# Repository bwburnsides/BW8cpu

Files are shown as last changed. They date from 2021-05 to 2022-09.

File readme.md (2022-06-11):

# 👾 BW8cpu

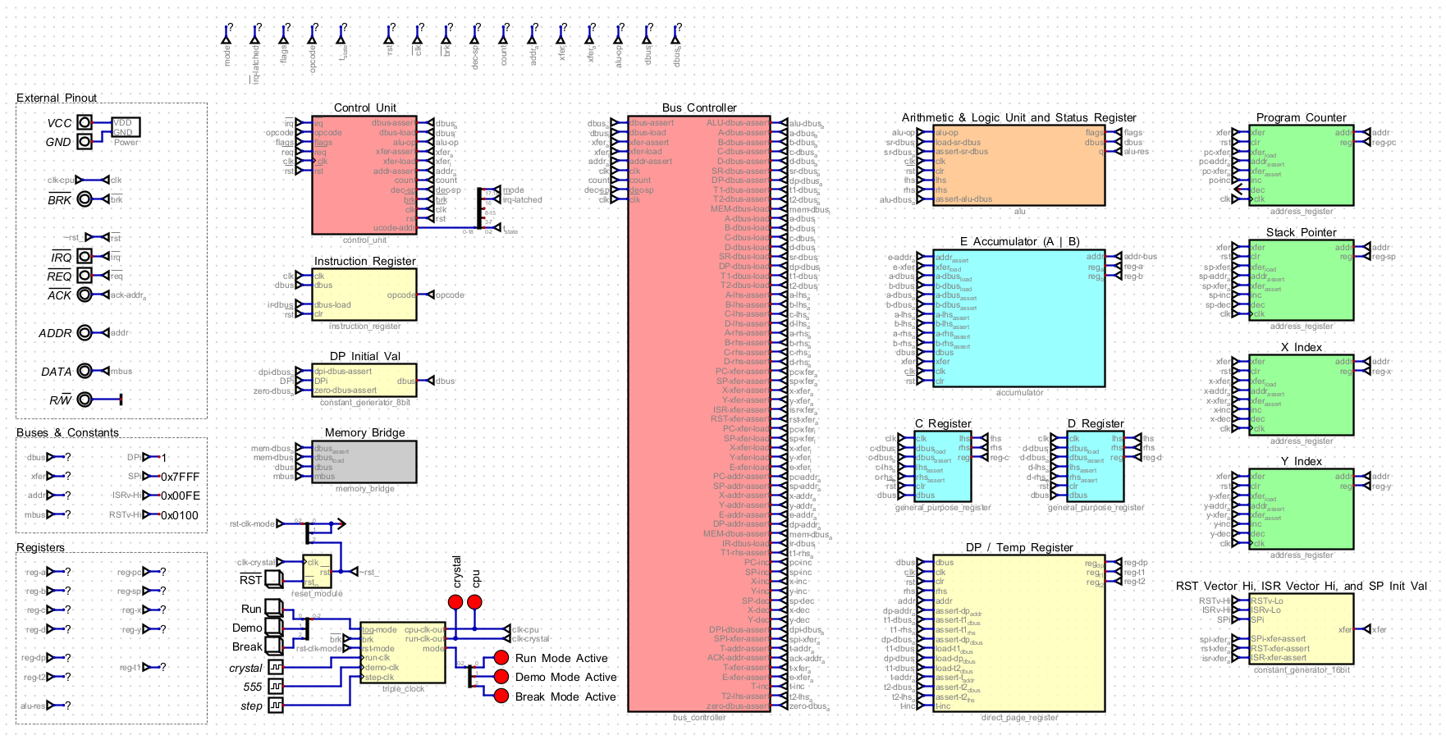
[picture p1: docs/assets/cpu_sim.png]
BW8cpu Digital Simulation top level view


The BW8cpu is a homemade CPU built with discrete CMOS logic chips on custom PCBs. It has a target clock rate of approximately 4 MHz, and is comparable to venerable 8-bit CPUs such as the MOS 6502, Zilog Z80, Motorola 6809, and Intel 8088.

A larger computer system is built around the CPU in the form of a full peripheral suite that allows the BW8cpu to function as a machine similar to the Commodore 64, Apple II, or NES. From a hardware perspective, the BW8cpu matches or maybe exceeds these systems in capability and usability in many regards. Its my hope that the system will eventually exceed its predecessors from a software perspective as well.

The project is originally inspired by Ben Eater's [8-bit breadboard CPU](https://eater.net/8bit) and his [breadboard MOS 6502 computer](https://eater.net/6502). However, ultimately the micro-architecture takes more cues from James Sharman's [8-bit pipelined CPU](https://www.youtube.com/watch?v=3iHag4k4yEg&list=PLFhc0MFC8MiCDOh3cGFji3qQfXziB9yOw). This project would not be possible without the support of many individuals present on James' Discord server, notably [rj45](https://github.com/rj45/rj32), Quandary, Artentus, and [Louis Jewett](https://www.youtube.com/channel/UCsxBT-Jh5pMDU-uEN_EUXtg/featured).

This project is extremely ambitious and long running. This repository will maintain documentation and descriptions of the existent and planned features, as well as supporting schematics and source code files.

## Features

- 8-bit CPU with 20-bit memory addressing, 8-bit IO addressing
- Up to 512 opcodes across 50 instructions (CISC ISA)
- 4x 8-bit General Purpose Registers (A, B, C, D)
- Full 16-bit Stack Pointer (SP) and Program Counters (PC)
- Configurable Direct Page addressing (movable Zero Page)
- Two 16-bit General Purpose Pointers (X, Y)
- 16-function ALU with 4 flags (Carry, Zero, Overflow, Sign)
- IRQ and NMI inputs
- Bus arbitration, allowing for DMA control
- Thin supervisor mode

## Architecture Overview

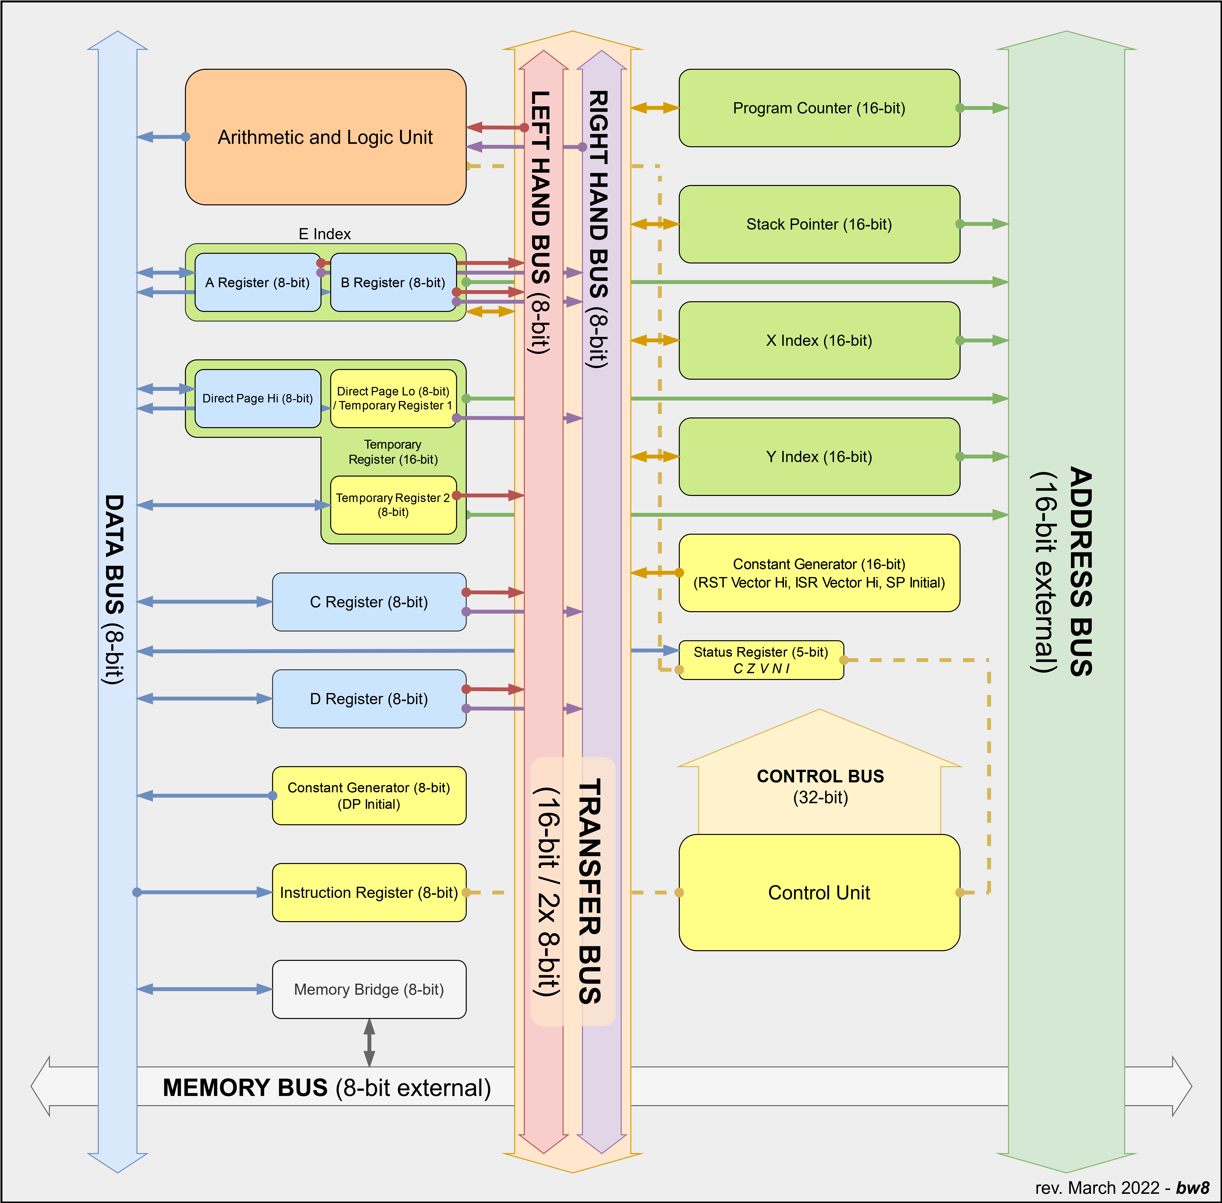
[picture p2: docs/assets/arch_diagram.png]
architecture diagram of BW8cpu


- [von Neumann architecture](https://en.wikipedia.org/wiki/Von_Neumann_architecture) with shared program and data address space
- Vertical microcode (heavily encoded) with 32-bit Control Bus
- Direct to address bus assertions without MAR
- No instruction pipelining - up to 8 clocks / instruction

## Expansion & Peripherals

- IO is memory mapped
- Reference Memory Map features:
    - 256 bytes IO space
    - 31.75 KB fixed RAM space
    - 32 KB total bankable space (4x 8 KB banks)
- Plans for full peripheral suite:
    - Programmable Interrupt Controller with 8 interrupt sources
    - VGA Video Card with output at 320x240 with 40x30 tilemap, hardware scrolling, and hardware sprite support
    - PS/2 keyboard input
    - Programmable Sound Generator with 4 voices
    - SPI Controller for SD card-based persistent storage
    - RS-232 UART networking interface
    - DMA Controller for fast block copies

## Tool Chain

- Simulation with [Digital](https://github.com/hneemann/Digital)
- Emulation with C
- Schematics and PCB layout with [KiCAD](https://www.kicad.org/)
- Assembler with [customasm](https://github.com/hlorenzi/customasm)
- Microcode development with Python

## Explore

🔧 [ISA](docs/instruction-set-architecture.md)

🧮 [ALU](docs/arithmetic-logic-unit.md)

🚥 [CU](docs/control-unit.md)

📺 [VGA](docs/video-card.md)

💾 [SPI](docs/spi.md)

📢 [PSG](docs/sound-card.md)

📡 [UART](docs/uart.md)

🎛 [Emulator](docs/emulator.md)

🎯 [Simulator](docs/simulator.md)

🗺 [Memory Map](docs/memory-map.md)

🏗 [Assembler](docs/assembler.md)

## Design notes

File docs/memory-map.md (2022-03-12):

# 🗺 Memory Map

The memory map was designed to maximize contiguous RAM space and provide ample banking to work around the 64 KB addressing limitation imposed by the 16-bit address bus.

    $E000 - $FFFF:   Banked RAM (8K)
    $C000 - $DFFF:   Banked RAM (8K)
    $A000 - $BFFF:   Banked RAM (8K)
    $8000 - $9FFF:   Banked RAM (8K)
    $0100 - $7FFF:   Fixed RAM (31.75K)
    $0000 - $00FF:   MMIO (256B)

This memory map provides just-shy of 32 KB of contiguous fixed RAM, and then another 32 KB of contiguous banked RAM in the form of 4x 8 KB banked regions. The first page of memory is allocated to memory mapped IO, the only form of IO in the system. Specifications of the active page for each bank will be done via 4x 1-byte registers in the MMIO region. This region will be divided into 16 equally sized IO ports, each afforded 16 IO registers. Here is a potential utilization scheme for the IO ports:

1. Programmable Interrupt Controller 1 (PIC)
2. Programmable Interrupt Controller 2
3. Memory Mapping Unit (MMU)
4. [UART](uart.md)
5. [SPI Bus](spi.md)
6. [Video Card](video-card.md)
7. [Sound Card](sound-card.md)
8. Sound Card 2
9. DMA Controller
10. PS/2 Keyboard Controller
...

Note that these IO devices largely correspond to those mentioned in the [readme](../readme.md). The new comers are the PIC and the MMU. The PIC is responsible for coalescing interrupts from multiple sources into a single IRQ input for the CPU. It contains registers for specifying the addresses of unique ISRs for each interrupt source. When the CPU reads from its ISR Vector, the PIC is responsible for making the highest-priority, non-masked, active interrupt's ISR address available at the vector location. The MMU contains registers used to configure the active page in each bankable location, as described above.

Note that the Sound Card and the PIC each use 2 IO ports a piece - this is due to the number of expected registers each device will require. I've elected to keep the number of registers per IO port relatively small, as doing so allows for devices which do in fact only need a few registers to be integrated in a less wasteful manner.

Another useful aspect of this memory configuration is that nearly the entire address space is covered by RAM, rather than ROM. This allows greater flexibility and usage of the address space, as all regions will allow writes. In order to facilitate this, a sub circuit will hold the CPU in reset while a ROM is copied into RAM. At runtime, this ROM becomes inactive. The copier circuit will initialize the entire low 32 KB of the address space, which has the side effect that the ROM can be used to initialize writable IO registers are pre-runtime.

The initial location of the DP and the SP are specified by the state of Constant Generators internal to the CPU. These are configurable via DIP switches on the appropriate CG boards. However, both values can be modified at runtime, should the user decide to relocate the stack or direct page. This can be done with the appropriate MOV opcodes made available in the Instruction Set.

The bank select registers will use all 8-bits to select a region of physical RAM to map into the bank regions. As the regions are 8 KB in size, this gives 2^8 * 8 KB = 2 MB of physical RAM accessible to the system. In fact, even the low 31.75 KB of RAM will map into this physical space.

If the decoded address belongs to the highest 32 KB of the physical RAM, then any writes will also be pushed through to VRAM. Effectively, this region shadows VRAM. It allows for any of the four banks to be used for VRAM manipulation, and it removes all potential contention issues for VRAM reads.

Both this, as well as the ROM copy-on-reset, are examples of RAM shadowing. The shadow regions are shown in blue, below.

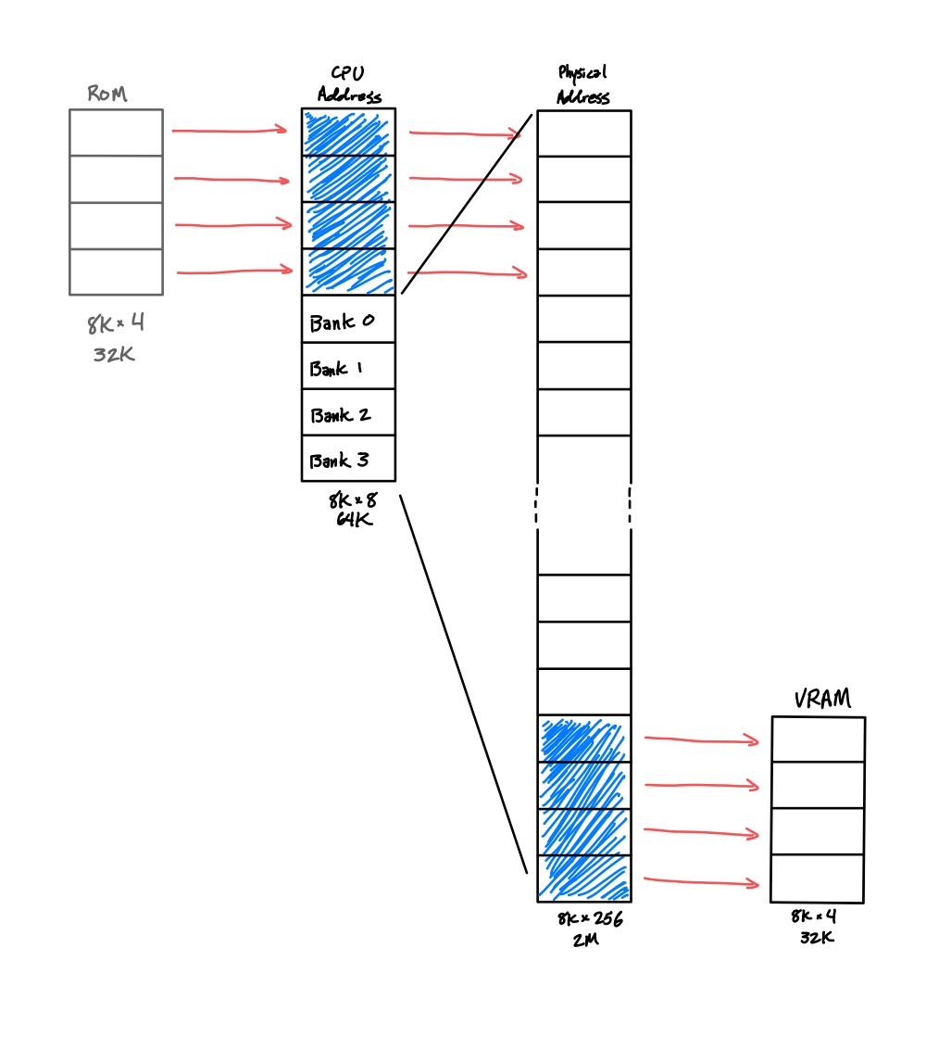
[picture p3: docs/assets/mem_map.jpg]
mem map diagram of BW8comp


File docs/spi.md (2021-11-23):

# 💾 SPI

The SPI peripheral's main reason for existing is to provide a hardware interface to SD cards, such that they may be used as a persistent storage medium for the BW8cpu.

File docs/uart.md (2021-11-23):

# 📡 UART

The UART allows for bidirectional communication between the CPU and another computer or controller.

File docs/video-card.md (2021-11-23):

# 📺 VGA

The premier BW8cpu peripheral is the VGA video card. This peripheral is similar to the NES's PPU. It runs in a reduced VGA 640x480 mode, producing an output of 320x240 pixels. Although a portion of the MMIO's 256 byte page will be allocated to the video card, the frame buffer will be accessible as one of the 16 KB banks in the top 16 KB of the address space. The card uses a tile and sprite system with 8x8 resolution. This 16 KB region allows for the background and sprite tables to be edited and accessed with the full power of the ISA's complex addressing modes. With 8x8 tile resolution, the VGA card will be capable of displaying 40 columns by 30 rows of text.

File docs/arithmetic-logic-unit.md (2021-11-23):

# 🧮 ALU

The arithmetic and logic unit is divided into 5 sections:

1. Instruction Decoder Unit
2. Flag Determination Unit
3. Arithmetic Unit
4. Logic Unit
5. Shift Unit

The ALU is controlled via the Control Unit's 5-bit ALU-op field on the 32-bit Control Bus. The IDU is responsible for decoding this 5-bit field into all the control signals needed by the ALU. The IDU is implemented via a diode matrix, and the 5-bit ALU-op allows for up to 32 unique instructions to be performed by the ALU. However, the IDU implements only 30 of them, and even fewer are used by the reference ISA. The operations are presented below - you will see a strong similarity between these operations and the instructions that exist in the ISA.

| Operation | Description |
| --- | --- |
| NOP | No operation |
| ADD | Add |
| ADC | Add with carry |
| SUB | Subtract |
| SBB | Subtract with borrow |
| AND | Logical AND |
| OR | Logical OR |
| XOR | Logical XOR |
| NOT | Logical NOT |
| NEG | Two's complement negation |
| LSR | Logical right shift |
| LRC | Logical right shift with carry |
| ASR | Arithmetic right shift |
| INC | Increment |
| DEC | Decrement |
| SEI | Set I |
| CLI | Clear I |
| SEC | Set C |
| CLC | Clear C |
| SEV | Set V |
| CLV | Clear V |
| SEZ | Set Z |
| CLZ | Clear Z |
| SEN | Set N |
| CLN | Clear N |
| LHS | LHS to result |
| RHS | RHS to result |
| LHS_C | LHS with carry to result |
| RHS_C | RHS with carry to result |
| ZERO | Zero to result |

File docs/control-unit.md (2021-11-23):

# 🚥 CU

The CPU is orchestrated by the Control Unit, which takes in 19 bits of state input, and translates them to a 32 bit micro-instruction every clock cycle. Those 19 bits of state input are as follows

- 3 bits - Tstate
- 8 bits - opcode
- 5 bits - flags
- 1 bit - IRQ
- 2 bits - mode select

The 3 bits of Tstate allow an instruction to take up to 8 clock cycles. However, most instructions take less than that. Instruction with complex indexed addressing modes or things like subroutine jumps tend to take more clocks. Simple loads, stores, 8-bit ALU operations, and register moves are much quicker.

The 2 bits of mode select allow for 4 CPU modes to exist:

1. Normal
2. Extended 1
3. Extended 2
4. Reset

The CPU will be in reset mode at power-up. This mode ignores the current opcode value and instead orchestrates a series of micro-instructions that are responsible for setting up the initial Direct Page (DP) register value, the initial Stack Pointer (SP) value, clearing the registers, and reading the Reset Vector (RSTv). At the conclusion of this sequence, it exits reset mode. The remaining 3 CPU modes each contain up to 256 valid opcodes that the CU is capable of executing. Its here where the 768 opcode upper limit comes from.

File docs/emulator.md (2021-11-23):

# 🎛 Emulator

The emulator is microcode-specific and built in Rust.

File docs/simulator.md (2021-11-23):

# 🎯 Simulator

The simulator is IC-specific and created in Digital

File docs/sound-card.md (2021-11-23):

# 📢 PSG

The PSG will produce 4 voices of audio output. This allows for left and right sound channels that each include a background and foreground sound channel, which may be useful for simultaneous soundtrack and sound effect playback.

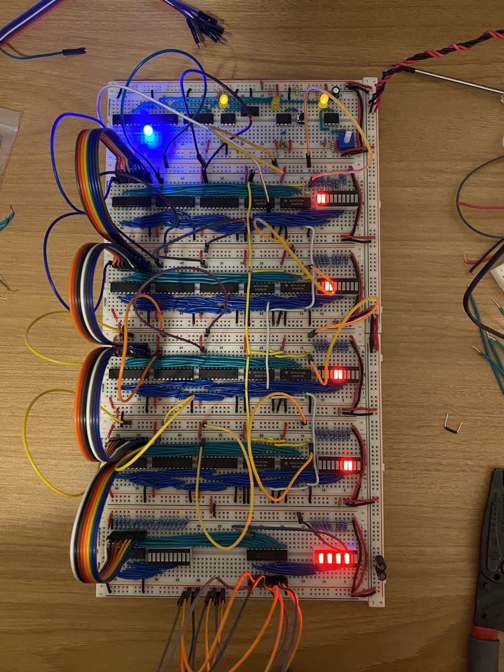
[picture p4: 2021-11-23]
docs/assets/breadboard_registers.jpg

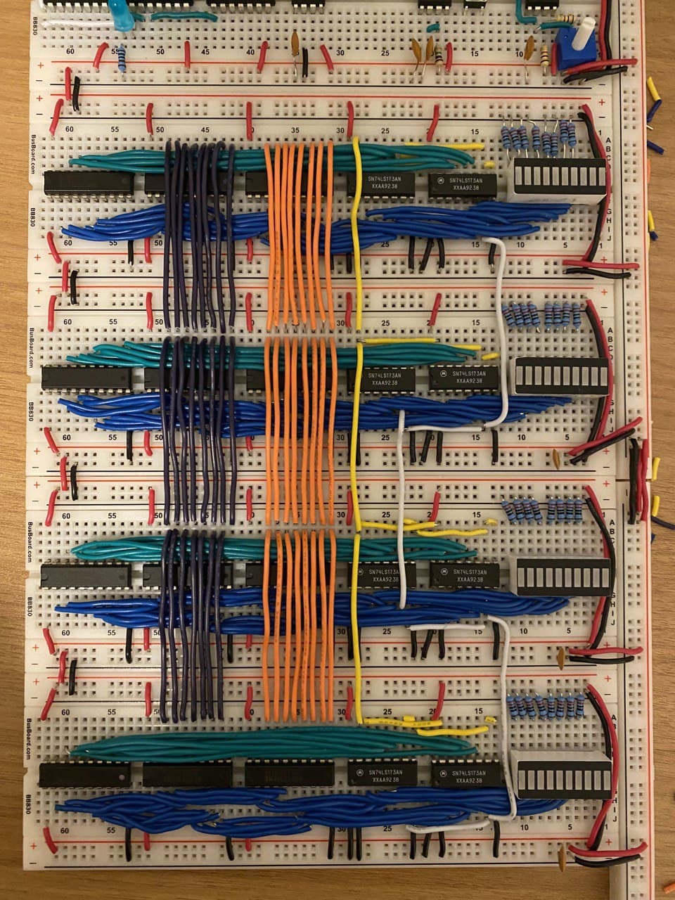
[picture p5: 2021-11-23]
docs/assets/breadboard_registers2.jpg

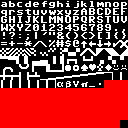
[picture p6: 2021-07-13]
graphics/modified_petscii_8x8.png

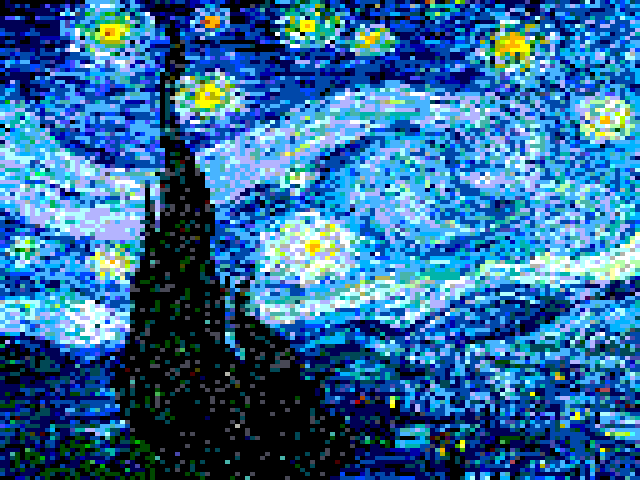
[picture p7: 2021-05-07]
graphics/starry.png

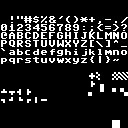
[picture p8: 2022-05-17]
graphics/system_bitmaps.png

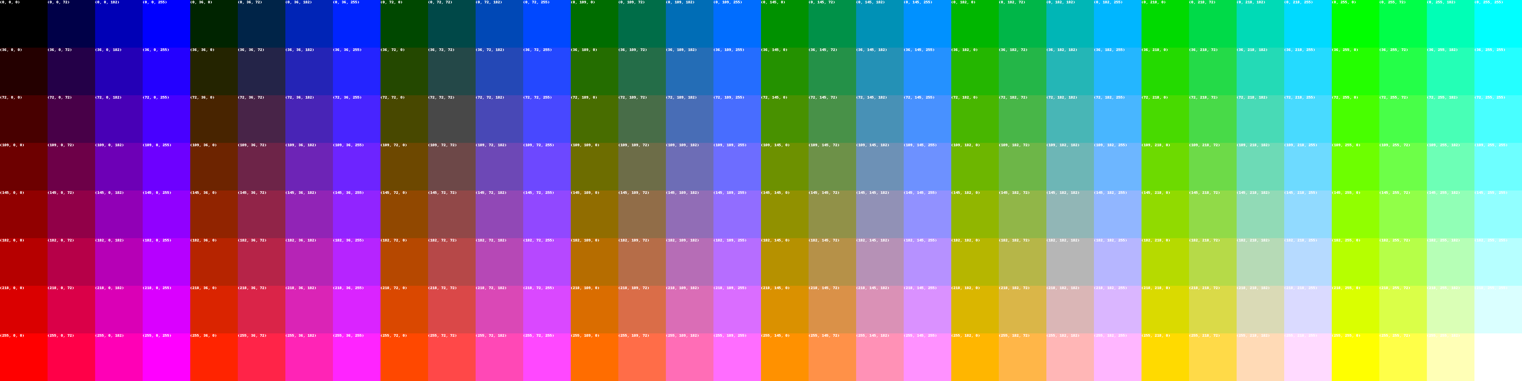
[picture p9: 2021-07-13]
graphics/256_labelled.png

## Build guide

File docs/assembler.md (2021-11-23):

# 🏗 Assembler

The assembler is built using customasm, a retargetable assembler built in Rust.

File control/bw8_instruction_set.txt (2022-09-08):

NOP*
EXT*
HALT

CLC*
CLI
CLV
SEC*
SEI

UBR
KBR

MOV_A_B*
MOV_A_C*
MOV_A_D*

MOV_B_A*
MOV_B_C*
MOV_B_D*

MOV_C_A*
MOV_C_B*
MOV_C_D*

MOV_D_A*
MOV_D_B*
MOV_D_C*

MOV_BR_A
MOV_A_BR

IN_A_PORT*
IN_A_X_IDX*
IN_A_X_A
IN_A_X_B
IN_A_X_C
IN_A_X_D
IN_A_Y_IDX*
IN_A_Y_A
IN_A_Y_B
IN_A_Y_C
IN_A_Y_D

IN_B_PORT*
IN_B_X_IDX*
IN_B_X_A
IN_B_X_B
IN_B_X_C
IN_B_X_D
IN_B_Y_IDX*
IN_B_Y_A
IN_B_Y_B
IN_B_Y_C
IN_B_Y_D

IN_C_PORT*
IN_C_X_IDX*
IN_C_X_A
IN_C_X_B
IN_C_X_C
IN_C_X_D
IN_C_Y_IDX*
IN_C_Y_A
IN_C_Y_B
IN_C_Y_C
IN_C_Y_D

IN_D_PORT*
IN_D_X_IDX*
IN_D_X_A
IN_D_X_B
IN_D_X_C
IN_D_X_D
IN_D_Y_IDX*
IN_D_Y_A
IN_D_Y_B
IN_D_Y_C
IN_D_Y_D

OUT_A_PORT*
OUT_A_X_IDX*
OUT_A_X_A
OUT_A_X_B
OUT_A_X_C
OUT_A_X_D
OUT_A_Y_IDX*
OUT_A_Y_A
OUT_A_Y_B
OUT_A_Y_C
OUT_A_Y_D

OUT_B_PORT*
OUT_B_X_IDX*
OUT_B_X_A
OUT_B_X_B
OUT_B_X_C
OUT_B_X_D
OUT_B_Y_IDX*
OUT_B_Y_A
OUT_B_Y_B
OUT_B_Y_C
OUT_B_Y_D

OUT_C_PORT*
OUT_C_X_IDX*
OUT_C_X_A
OUT_C_X_B
OUT_C_X_C
OUT_C_X_D
OUT_C_Y_IDX*
OUT_C_Y_A
OUT_C_Y_B
OUT_C_Y_C
OUT_C_Y_D

OUT_D_PORT*
OUT_D_X_IDX*
OUT_D_X_A
OUT_D_X_B
OUT_D_X_C
OUT_D_X_D
OUT_D_Y_IDX*
OUT_D_Y_A
OUT_D_Y_B
OUT_D_Y_C
OUT_D_Y_D

LOAD_A_IMM*
LOAD_A_ABS*
LOAD_A_X_IDX*
LOAD_A_X_A*
LOAD_A_X_B*
LOAD_A_X_C*
LOAD_A_X_D*
LOAD_A_Y_IDX*
LOAD_A_Y_A*
LOAD_A_Y_B*
LOAD_A_Y_C*
LOAD_A_Y_D*
LOAD_A_SP_IDX*
LOAD_A_SP_A*
LOAD_A_SP_B*
LOAD_A_SP_C*
LOAD_A_SP_D*

LOAD_B_IMM*
LOAD_B_ABS*
LOAD_B_X_IDX*
LOAD_B_X_A*
LOAD_B_X_B*
LOAD_B_X_C*
LOAD_B_X_D*
LOAD_B_Y_IDX*
LOAD_B_Y_A*
LOAD_B_Y_B*
LOAD_B_Y_C*
LOAD_B_Y_D*
LOAD_B_SP_IDX*
LOAD_B_SP_A*
LOAD_B_SP_B*
LOAD_B_SP_C*
LOAD_B_SP_D*

LOAD_C_IMM*
LOAD_C_ABS*
LOAD_C_X_IDX*
LOAD_C_X_A*
LOAD_C_X_B*
LOAD_C_X_C*
LOAD_C_X_D*
LOAD_C_Y_IDX*
LOAD_C_Y_A*
LOAD_C_Y_B*
LOAD_C_Y_C*
LOAD_C_Y_D*
LOAD_C_SP_IDX*
LOAD_C_SP_A*
LOAD_C_SP_B*
LOAD_C_SP_C*
LOAD_C_SP_D*

LOAD_D_IMM*
LOAD_D_ABS*
LOAD_D_X_IDX*
LOAD_D_X_A*
LOAD_D_X_B*
LOAD_D_X_C*
LOAD_D_X_D*
LOAD_D_Y_IDX*
LOAD_D_Y_A*
LOAD_D_Y_B*
LOAD_D_Y_C*
LOAD_D_Y_D*
LOAD_D_SP_IDX*
LOAD_D_SP_A*
LOAD_D_SP_B*
LOAD_D_SP_C*
LOAD_D_SP_D*

STORE_A_ABS*
STORE_A_X_IDX*
STORE_A_X_A*
STORE_A_X_B*
STORE_A_X_C*
STORE_A_X_D*
STORE_A_Y_IDX*
STORE_A_Y_A*
STORE_A_Y_B*
STORE_A_Y_C*
STORE_A_Y_D*
STORE_A_SP_IDX*
STORE_A_SP_A*
STORE_A_SP_B*
STORE_A_SP_C*
STORE_A_SP_D*

STORE_B_ABS*
STORE_B_X_IDX*
STORE_B_X_A*
STORE_B_X_B*
STORE_B_X_C*
STORE_B_X_D*
STORE_B_Y_IDX*
STORE_B_Y_A*
STORE_B_Y_B*
STORE_B_Y_C*
STORE_B_Y_D*
STORE_B_SP_IDX*
STORE_B_SP_A*
STORE_B_SP_B*
STORE_B_SP_C*
STORE_B_SP_D*

STORE_C_ABS*
STORE_C_X_IDX*
STORE_C_X_A*
STORE_C_X_B*
STORE_C_X_C*
STORE_C_X_D*
STORE_C_Y_IDX*
STORE_C_Y_A*
STORE_C_Y_B*
STORE_C_Y_C*
STORE_C_Y_D*
STORE_C_SP_IDX*
STORE_C_SP_A*
STORE_C_SP_B*
STORE_C_SP_C*
STORE_C_SP_D*

STORE_D_ABS*
STORE_D_X_IDX*
STORE_D_X_A*
STORE_D_X_B*
STORE_D_X_C*
STORE_D_X_D*
STORE_D_Y_IDX*
STORE_D_Y_A*
STORE_D_Y_B*
STORE_D_Y_C*
STORE_D_Y_D*
STORE_D_SP_IDX*
STORE_D_SP_A*
STORE_D_SP_B*
STORE_D_SP_C*
STORE_D_SP_D*

MOV_X_Y*
MOV_X_AB*
MOV_X_CD*

MOV_Y_X*
MOV_Y_AB*
MOV_Y_CD*

MOV_AB_X*
MOV_AB_Y*

MOV_CD_X*
MOV_CD_Y*

MOV_SP_X
MOV_X_SP

LOAD_X_IMM*
LOAD_X_ABS*
LOAD_X_X_IDX*
LOAD_X_Y_IDX*
LOAD_X_SP_IDX*

LOAD_Y_IMM*
LOAD_Y_ABS*
LOAD_Y_X_IDX*
LOAD_Y_Y_IDX*
LOAD_Y_SP_IDX*

STORE_X_ABS*
STORE_X_X_IDX*
STORE_X_Y_IDX*
STORE_X_SP_IDX*

STORE_Y_ABS*
STORE_Y_X_IDX*
STORE_Y_Y_IDX*
STORE_Y_SP_IDX*

LEA_X_A
LEA_X_B
LEA_X_C
LEA_X_D
LEA_X_IDX*

LEA_Y_A
LEA_Y_B
LEA_Y_C
LEA_Y_D
LEA_Y_IDX*

LEA_SP_A
LEA_SP_B
LEA_SP_C
LEA_SP_D
LEA_SP_IDX*

ADC_A_A
ADC_A_B
ADC_A_C
ADC_A_D
ADC_A_IMM

ADC_B_A
ADC_B_B
ADC_B_C
ADC_B_D
ADC_B_IMM

ADC_C_A
ADC_C_B
ADC_C_C
ADC_C_D
ADC_C_IMM

ADC_D_A
ADC_D_B
ADC_D_C
ADC_D_D
ADC_D_IMM

SBC_A_A
SBC_A_B
SBC_A_C
SBC_A_D
SBC_A_IMM

SBC_B_A
SBC_B_B
SBC_B_C
SBC_B_D
SBC_B_IMM

SBC_C_A
SBC_C_B
SBC_C_C
SBC_C_D
SBC_C_IMM

SBC_D_A
SBC_D_B
SBC_D_C
SBC_D_D
SBC_D_IMM

AND_A_B
AND_A_C
AND_A_D
AND_A_IMM

AND_B_A
AND_B_C
AND_B_D
AND_B_IMM

AND_C_A
AND_C_B
AND_C_D
AND_C_IMM

AND_D_A
AND_D_B
AND_D_C
AND_D_IMM

OR_A_B
OR_A_C
OR_A_D
OR_A_IMM

OR_B_A
OR_B_C
OR_B_D
OR_B_IMM

OR_C_A
OR_C_B
OR_C_D
OR_C_IMM

OR_D_A
OR_D_B
OR_D_C
OR_D_IMM

XOR_A_A
XOR_A_B
XOR_A_C
XOR_A_D
XOR_A_IMM

XOR_B_A
XOR_B_B
XOR_B_C
XOR_B_D
XOR_B_IMM

XOR_C_A
XOR_C_B
XOR_C_C
XOR_C_D
XOR_C_IMM

XOR_D_A
XOR_D_B
XOR_D_C
XOR_D_D
XOR_D_IMM

NOT_A
NOT_B
NOT_C
NOT_D

NEG_A
NEG_B
NEG_C
NEG_D

SRC_A
SRC_B
SRC_C
SRC_D

ASR_A
ASR_B
ASR_C
ASR_D

INC_A
INC_B
INC_C
INC_D

INC_X*
INC_Y*

DEC_A
DEC_B
DEC_C
DEC_D

DEC_X*
DEC_Y*

PUSH_A*
PUSH_B*
PUSH_C*
PUSH_D*
PUSH_X*
PUSH_Y*

POP_A*
POP_B*
POP_C*
POP_D*
POP_X*
POP_Y*

CMP_A_A
CMP_A_B
CMP_A_C
CMP_A_D
CMP_A_IMM*

CMP_B_A
CMP_B_B
CMP_B_C
CMP_B_D
CMP_B_IMM*

CMP_C_A
CMP_C_B
CMP_C_C
CMP_C_D
CMP_C_IMM*

CMP_D_A
CMP_D_B
CMP_D_C
CMP_D_D
CMP_D_IMM*

TST_A
TST_B
TST_C
TST_D

JSR_ABS*
JSR_REL*
JSR_X
JSR_Y
RTS*
SWI
RTI

JMP_ABS*
JMP_REL*
JMP_X
JMP_Y

JO_ABS*
JO_REL*
JO_X
JO_Y

JNO_ABS*
JNO_REL*
JNO_X
JNO_Y

JS_ABS*
JS_REL*
JS_X
JS_Y

JNS_ABS*
JNS_REL*
JNS_X
JNS_Y

JE_ABS*
JE_REL*
JE_X
JE_Y

JNE_ABS*
JNE_REL*
JNE_X
JNE_Y

JC_ABS*
JC_REL*
JC_X
JC_Y

JNC_ABS*
JNC_REL*
JNC_X
JNC_Y

JBE_ABS*
JBE_REL*
JBE_X
JBE_Y

JA_ABS*
JA_REL*
JA_X
JA_Y

JL_ABS*
JL_REL*
JL_X
JL_Y

JGE_ABS*
JGE_REL*
JGE_X
JGE_Y

JLE_ABS*
JLE_REL*
JLE_X
JLE_Y

JG_ABS*
JG_REL*
JG_X
JG_Y

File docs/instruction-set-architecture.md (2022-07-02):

# 🔧 BW8 Instruction Set Architecture Specification

The BW8cpu instruction set contains the following instructions. Many instructions has several opcodes that implement various combinations of operands and addressing mode variations on their base behavior. These will be discussed below.

Mnemonic                                        | Name                           
----------------------------------------------- | ------------------------------
[`NOP`](#nop---no-operation)                    | No Operation                   
[`CLC`](#clc---clear-carry)                     | Clear Carry                    
[`CLI`](#cli---enable-interrupts)               | Disable Interrupts
[`CLV`](#clv---clear-overflow)                  | Clear Overflow                 
[`SEC`](#sec---set-carry-flag)                  | Set Carry                      
[`SEI`](#sei---disable-interrupts)              | Enable Interrupts             
[`UBR`](#ubr---enable-user-bank-register)       | Enable User Bank Register
[`SBR`](#sbr---enable-supervisor-bank-register) | Enable Supervisor Bank Register     
[`IN`](#in---read-io-port)                      | IO Input
[`OUT`](#out---write-io-port)                   | IO Output             
[`MOV`](#mov---move-register)                   | Move Register                  
[`LOAD`](#load---load-register)                 | Load Register                  
[`STORE`](#store---store-register)              | Store Register                 
[`LEA`](#lea---load-effective-address)          | Load Effective Address         
[`ADC`](#adc---add-with-carry)                  | Add with Carry                 
[`SBB`](#sbb---subtract-with-borrow)            | Subtract with Borrow           
[`AND`](#and---bitwise-and)                     | Bitwise AND                    
[`OR`](#or---bitwise-or)                        | Bitwise OR                     
[`XOR`](#xor---bitwise-xor)                     | Bitwise XOR                    
[`NOT`](#not---bitwise-inversion)               | Bitwise NOT                    
[`NEG`](#neg---2s-complement-negation)          | 2s Complement Negation         
[`SRC`](#shr---logical-shift-right-with-carry)  | Logical Shift Right with Carry 
[`ASR`](#asr---arithmetic-shift-right)          | Arithmetic Shift Right         
[`INC`](#inc---increment)                       | Increment                      
[`DEC`](#dec---decrement)                       | Decrement                      
[`PUSH`](#push---push-to-stack)                 | Push to Stack                  
[`POP`](#pop---pop-from-stack)                  | Pop from Stack                 
[`CMP`](#cmp---compare)                         | Compare                       
[`TST`](#tst---bit-test)                        | Bit Test                       
[`RTI`](#rti---return-from-interrupt)           | Return from Interrupt          
[`JSR`](#jsr---jump-to-subroutine)              | Jump to Subroutine             
[`RTS`](#rts---return-from-subroutine)          | Return from Subroutine   
[`JMP`](#jmp---unconditional-jump)              | Jump                           
[`JO`](#jo---jump-if-overflow)                  | Jump if Overflow               
[`JNO`](#jno---jump-if-not-overflow)            | Jump if not Overflow           
[`JS`](#js---jump-if-sign)                      | Jump if Sign                   
[`JNS`](#jns---jump-if-not-sign)                | Jump if not Sign               
[`JE`](#je---jump-if-equal)                     | Jump if Equal                  
[`JNE`](#jne---jump-if-not-equal)               | Jump if not Equal              
[`JC`](#jc---jump-if-carry)                     | Jump if Carry                  
[`JNC`](#jnc---jump-if-not-carry)               | Jump if not Carry              
[`JBE`](#jbe---jump-if-below-or-equal)          | Jump if Below or Equal         
[`JA`](#ja---jump-if-above)                     | Jump if Above                  
[`JL`](#jl---jump-if-less)                      | Jump if Less                   
[`JGE`](#jge---jump-if-greater-or-equal)        | Jump if Greater or Equal       
[`JLE`](#jle---jump-if-less-or-equal)           | Jump if Less or Equal          
[`JG`](#jg---jump-if-greater)                   | Jump if Greater                

The BW8 has an 8-bit Instruction Register, so there is some trickery involved to support up to 512 opcodes, rather than just 256. This is done with the `EXT` instruction. This is a 1 byte, 1 cycle instruction which transitions the CPU from normal "`NRM`" mode to extended "`EXT`" mode, and then fetches the next instruction. This next instruction is interpretted differently due to the system being in `EXT` Mode. At the conclusion of these instructions, they return the CPU to Normal (`NRM`) Mode. Through this mechanism, the CPU can ascribe two different meanings to each 8-bit opcode value, yielding a total of 512 opcodes.

The `NRM` Mode instructions are those which are commonly used, have long cycle counts, or have larger operand counts. The idea is to limit the cycle penalty incurred by `EXT` Mode opcodes to those which already execute quickly, or are not commonly used. In addition, by making sure that large operand count instructions exist in NRM Mode, we can reduce the program size penalty down too.

# Programming Model

The CPU programming model includes four 8-bit General Purpose Registers (`gpr`): `a`, `b`, `c`, `d`, and two 16-bit General Purpose Pointers (`gpp`): `x`, `y`. There are five special purpose programmer facing registers:

1. `dp` - 8-bit, the location of the Direct Page
2. `ab` - 16-bit, a pseudo register constructed with `a` in the high byte and `b` in the low byte
3. `cd` - 16-bit, a psuedo register constructed with `c` in the high byte and `d` in the low byte
4. `sp` - 16-bit, the system Stack Pointer
5. `br` - 4-bit, the user Bank Register

These registers have limited direct instruction support, and are generally interacted with via `MOV`s. The `ab` and `cd` registers provide a mechanism for constructing 16-bit results that can be loaded into the GPPs or the SP. The combination of `gpp` and `sp` is known as the pointers (`ptr`).

Additionally, there is the Status Register (`sr`) which stores the following CPU flags. `sr` is not user facing, meaning that the user can not explicity load or store values into it. Nonetheless, the value of each bit in the register can be directly or indirectly managed by the program via select instructions in the ISA. The flags that each instruction modify are denoted in the instruction descriptions below.

1. Zero (`Z`)
2. Carry (`C`)
3. Negative (`N`)
4. Overflow (`V`)
5. Interrupt Enable (`I`)
6. Use User Bank Register (`U`)
7. ~Supervisor Enable (`~S`)

The first four of these are primarily set by the result of a recent ALU calculation. The Interrupt Enable flag is used to enable or disable maskable interrupt requests (IRQ), and is managed directly by the programmer via `SEI` and `CLI`. Finally, the `U` flag is intended for use within supervisor code, in order to give access to user address spaces.

In the subsequent section, the size of an instruction is given as the total number of bytes required to execute the instruction. This includes the optional prefix `EXT` byte, the opcode itself, and any operands following the opcode in the instruction stream. For this reason, the `BW8` ISA can be thought of as a variable-length instruction set.

# Addressing Modes

Addressing Modes specify the source and destination of instructions. Many instructions support multiple addressing modes - these are described in the subsequent instruction description section. Below are descriptions of all addressing modes present in the ISA.

- *Implied*: There is no relevant operand source or destination, or they are implied directly by the opcode.

- *Register Direct*: There is no effective address; all operands are in registers which are implied by the opcode.

- *Immediate*: There is no effective address; the operand is the one or two bytes following the opcode in the instruction stream, depending on the target of the instruction.

- *Absolute*: The effective address is given as a two-byte absolute address which follows the opcode in Big Endian order.

- *Direct*: The effective address is given as a one-byte direct page address which follows the opcode.

- *Register Indirect*: The effective address is the address in a pointer register implied by the opcode.

- *Indexed Indirect*: The effective address is computed by adding a signed 8-bit index to a pointer register's contents. Both the pointer register and the index source are implied in the opcode.

- *Relative*: The effective address is computed by adding a signed 8-bit offset to the Program Counter. The offset source is the byte following the opcode.

# Instruction Details
## `NOP` - No Operation

Field  | Value
------ | ---
Type   | `NRM`
Size   | 1
Cycles | 2
Mode   | Implied

Perform no operation.

Assembly:

    nop

Does nothing, and then continues.

## `CLC` - Clear Carry

Field  | Value
------ | ---
Type   | `NRM`
Size   | 1
Cycles | 2
Mode   | Implied

| `Z` | `C` | `N` | `V` | `I`
| --- | --- | --- | --- | ---
|  -  |  0  |  -  |  -  |  -

Clears the Carry Flag.

Assembly:

    clc

Sets the SR's `C` flag to 0.

## `CLI` - Disable Interrupts

Field  | Value
------ | ---
Type   | `NRM`
Size   | 1
Cycles | 2
Mode   | Implied

| `Z` | `C` | `N` | `V` | `I`
| --- | --- | --- | --- | ---
|  -  |  -  |  -  |  -  |  0

Disable maskable interrupts, set the Interrupt Enable flag `I` to 0.

Assembly:

    cli

Sets the SR's `I` flag to 0.

## `CLV` - Clear Overflow

Field  | Value
------ | ---
Type   | `NRM`
Size   | 1
Cycles | 2
Mode   | Implied

| `Z` | `C` | `N` | `V` | `I`
| --- | --- | --- | --- | ---
|  -  |  -  |  -  |  0  |  -

Clear the Overflow Flag `V` to 0. 

Assembly:

    clv

Sets the SR's `V` flag to 0.

## `SEC` - Set Carry Flag

Field  | Value
------ | ---
Type   | `NRM`
Size   | 1
Cycles | 2
Mode   | Implied

| `Z` | `C` | `N` | `V` | `I`
| --- | --- | --- | --- | ---
|  -  |  1  |  -  |  -  |  -

Set the Carry Flag `C` to 1.

Assembly:

    sec

## `SEI` - Enable Interrupts

Field  | Value
------ | ---
Type   | `NRM`
Size   | 1
Cycles | 2
Mode   | Implied

| `Z` | `C` | `N` | `V` | `I`
| --- | --- | --- | --- | ---
|  -  |  -  |  -  |  -  |  1

    sei

Sets the SR's `I` flag to 1.

## `IN` - Read IO Port

Field | Value
----- | -----
Type  | `EXT`
Size  | varies
Cycles | varies
Mode | varies

Input one byte of data from the specified IO port. `in` opcods which follow the first form below are 3 bytes in size. Opcodes which follow the second form are 4 bytes in size.

Assembly:

    in {dst: gpr}, <{port: u8}>
    in [!{dp: u8}], <{port: u8}>

## `OUT` -- Write IO Port

Field | Value
----- | -----
Type  | `EXT`
Size  | varies
Cycles | varies
Mode | varies

Output one byte of data to the specified IO port. `out` opcodes which follow the first form are 3 bytes in size. Otherwise, they are 4 bytes in size.

Assembly:

    out <{port: u8}>, {src: gpr}
    out <{port: u8}>, [!{dp: u8}]
    out <{port: u8}>, #{imm: i8}

## `MOV` - Move Register

Field  | Value
------ | ---
Type   | `NRM`
Size   | 1
Cycles | 2
Mode   | Implied

The `MOV` instruction has both 8-bit and 16-bit versions. These versions have separate sets of allowed destinations and sources. The format of the `MOV` instruction is: `mov dst, src`. It is illegal for `dst` to match `src`.

### 8-bit `MOV`

Source: `gpr`
Destination: `gpr`

Extraneous pairs:
    `mov a, dp`
    `mov dp, a`
    `mov a, br`
    `mov br, a`

### 16-bit `MOV`

Source: `x`, `y`, `ab`, `cd`
Destination: `x`, `y`, `ab`, `cd`

Extraneous pairs:
    `mov x, sp`
    `mov sp, x`

Note:
    `ab` and `cd` being used as a `src`-`dst` (or `dst`-`src`) pair is illegal. The assembler should implement these instructions as pseudo instructions consisting of two 8-bit `MOV`s.

## `LOAD` - Load Register

Field  | Value
------ | ---
Type   | `NRM`
Size   | varies
Cycles | varies
Mode   | varies

The `LOAD` instruction has varying specifications for the 8-bit and 16-bit versions.

### 8-bit `LOAD`

    load {dst: gpr}, #{imm: i8}
    load {dst: gpr}, [{abs: u16}]
    load {dst: gpr}, [!{dp: u8}]
    load {dst: gpr}, [{ptr}, #{idx: s8}]
    load {dst: gpr}, [{ptr}, {idx: gpr}]

### 16-bit `LOAD`

## `STORE` - Store Register

`STORE` instructions write a register's contents to memory. They are the reciprocal to the [`LOAD`](#load---load-register) instructions. They have identical modes and restrictions as the `LOAD` instructions do, with the exceptions that the **Immediate** mode does not exist, as that doesn't make sense in the context of a memory write, and the cycle counts may be different. Those are currently TBD.

## `LEA` - Load Effective Address

Field  | Value
------ | ---
Type   | `NRM`
Size   | 1
Cycles | TBD
Mode   | Indexed Indirect

Destinations: GPPs
Indirection Sources: GPPs or `sp`
Index Sources: GPRs

The `LEA` instructions perform the same address calculation that occurs with Indexed Indirect loads and stores, but don't actually perform the memory operation.

## `ADC` - Add with Carry

Field  | Value
------ | ---
Type   | varies
Size   | varies
Cycles | varies
Mode   | varies

| `Z` | `C` | `N` | `V` | `I`
| --- | --- | --- | --- | ---
|  +  |  +  |  +  |  +  |  -

`ADC` instructions follow the rules of [Binary Math Operations](#binary-math-operations).

## `SBB` - Subtract with Borrow

Field  | Value
------ | ---
Type   | varies
Size   | varies
Cycles | varies
Mode   | varies

| `Z` | `C` | `N` | `V` | `I`
| --- | --- | --- | --- | ---
|  +  |  +  |  +  |  +  |  -

`SBB` instructions follow the rules of [Binary Math Operations](#binary-math-operations).

## `AND` - Bitwise AND

Field  | Value
------ | ---
Type   | varies
Size   | varies
Cycles | varies
Mode   | varies

| `Z` | `C` | `N` | `V` | `I`
| --- | --- | --- | --- | ---
|  +  |  -  |  +  |  -  |  -

`AND` instructions follow the rules of [Binary Math Operations](#binary-math-operations).

## `OR` - Bitwise OR

Field  | Value
------ | ---
Type   | varies
Size   | varies
Cycles | varies
Mode   | varies

| `Z` | `C` | `N` | `V` | `I`
| --- | --- | --- | --- | ---
|  +  |  -  |  +  |  -  |  -

`OR` instructions follow the rules of [Binary Math Operations](#binary-math-operations).

## `XOR` - Bitwise XOR

Field  | Value
------ | ---
Type   | varies
Size   | varies
Cycles | varies
Mode   | varies

| `Z` | `C` | `N` | `V` | `I`
| --- | --- | --- | --- | ---
|  +  |  -  |  +  |  -  |  -

`XOR` instructions follow the rules of [Binary Math Operations](#binary-math-operations).

## `NOT` - Bitwise Inversion

Field  | Value
------ | ---
Type   | `EXT`
Size   | varies
Cycles | varies
Mode   | varies

| `Z` | `C` | `N` | `V` | `I`
| --- | --- | --- | --- | ---
|  +  |  -  |  +  |  -  |  -

`NOT` instructions follow the rules of [Unary Math Operations](#unary-math-operations).

## `NEG` - 2s Complement Negation

Field  | Value
------ | ---
Type   | `EXT`
Size   | varies
Cycles | varies
Mode   | varies

| `Z` | `C` | `N` | `V` | `I`
| --- | --- | --- | --- | ---
|  -  |  -  |  -  |  -  |  -

`NEG` instructions follow the rules of [Unary Math Operations](#unary-math-operations).

## `SRC` - Logical Shift Right with Carry

Field  | Value
------ | ---
Type   | `EXT`
Size   | varies
Cycles | varies
Mode   | varies

| `Z` | `C` | `N` | `V` | `I`
| --- | --- | --- | --- | ---
|  +  |  +  |  +  |  -  |  -

`SRC` instructions follow the rules of [Unary Math Operations](#unary-math-operations).

## `ASR` - Arithmetic Shift Right

Field  | Value
------ | ---
Type   | `EXT`
Size   | varies
Cycles | varies
Mode   | varies

| `Z` | `C` | `N` | `V` | `I`
| --- | --- | --- | --- | ---
|  +  |  +  |  +  |  -  |  -

`ASR` instructions follow the rules of [Unary Math Operations](#unary-math-operations).

## `INC` - Increment

Field  | Value
------ | ---
Type   | `EXT`
Size   | varies
Cycles | varies
Mode   | varies

Addressing Modes:

**Implied**

Size: 2
Cycles: TBD

Implied `INC` instructions have a source which is either a GPR or a GPP.

**Direct Page**

Size: 3
Cycles: TBD

Direct Page `INC` instructions operate on 8-byte values only.

### Flag Modification
If the source is a GPP, then no flags are modified. Otherwise, the following is true:

| `Z` | `C` | `N` | `V` | `I`
| --- | --- | --- | --- | ---
|  +  |  +  |  +  |  -  |  -

## `DEC` - Decrement

Field  | Value
------ | ---
Type   | `EXT`
Size   | varies
Cycles | varies
Mode   | varies

Addressing Modes:

**Implied**

Size: 2
Cycles: TBD

Implied `DEC` instructions have a source which is either a GPR or a GPP.

**Direct Page**

Size: 3
Cycles: TBD

Direct Page `DEC` instructions operate on 8-byte values only.

### Flag Modification
If the source is a GPP, then no flags are modified. Otherwise, the following is true:

| `Z` | `C` | `N` | `V` | `I`
| --- | --- | --- | --- | ---
|  +  |  +  |  +  |  -  |  -

## `PUSH` - Push to Stack

Field  | Value
------ | ---
Type   | `EXT`
Size   | 2
Cycles | varies
Mode   | Implied

Sources: GPRs, GPPs, Status Register (SR)

## `POP` - Pop from Stack

Field  | Value
------ | ---
Type   | `EXT`
Size   | 2
Cycles | varies
Mode   | Implied

Sources: GPRs, GPPs, Status Register (SR)

## `CMP` - Compare

Field  | Value
------ | ---
Type   | varies
Size   | varies
Cycles | varies
Mode   | varies

| `Z` | `C` | `N` | `V` | `I`
| --- | --- | --- | --- | ---
|  +  |  +  |  +  |  +  |  -

`CMP` instructions perform a subtract without borrow but discard the result. The purpose of this instruction is to set the SR flags appropriately, and is commonly used before performing a conditional jump. They closely follow the Binary Math Operations rules, with the exception that immediates are not a supported right hand operand.

*TODO*: Compare with Immediates are very useful. Add these in once `LSR` instructions have been removed.

## `TST` - Bit Test

Field  | Value
------ | ---
Type   | `EXT`
Size   | varies
Cycles | varies
Mode   | varies

| `Z` | `C` | `N` | `V` | `I`
| --- | --- | --- | --- | ---
|  +  |  -  |  +  |  -  |  -

`TST` instructions perform a Bitwise `AND` operation of the operand with itself, but then discards the result. The purpose of this instruction is to set the SR flags appropriately, and is commonly used before performing a conditional jump. They closed follow the Unary Math Operations rules.

## `WAI` - Wait for Interrupt

Field  | Value
------ | ---
Type   | `NRM`
Size   | 1
Cycles | varies
Mode   | Implied

The `WAI` instruction causes execution to suspend until an IRQ is received. This instruction has two distinct behaviors, depending on the state of the SR's `I` flag prior to it beginning execution.

- `I = 0`: When an IRQ is received, a context shift to the appropriate ISR occurs. When the routine returns, execution resumes after the `WAI` instruction.

- `I = 1`: When an IRQ is recieved, no context shift occurs and execution continues after the `WAI` instruction. This can be used to process interrupts "in-line".

## `RTI` - Return from Interrupt

Field  | Value
------ | ---
Type   | `NRM`
Size   | 1
Cycles | TBD
Mode   | Implied

The `RTI` instruction performs a context switch away from an ISR to the previously executing code by restoring the Program Counter, the Status Register, and the Interrupt Inhibit flag.

## `JSR` - Jump to Subroutine

Field  | Value
------ | ---
Type   | varies
Size   | varies
Cycles | varies
Mode   | varies

`JSR` instructions execute a function call by saving the Program Counter to the stack and loading the source to the Program Counter to execute a jump. The size and type of the opcode varies based on its Addressing Mode.

Addressing Modes:

**Absolute**

Type: `NRM`
Size: 3
Cycles: TBD

**Relative**

Type: `NRM`
Size: 2
Cycles: TBD

**Indirect**

Indirection Sources: GPPs
Type: `EXT`
Size: 2
Cycles: TBD

## `RTS` - Return from Subroutine

Field  | Value
------ | ---
Type   | NRM
Size   | 1
Cycles | TBD
Mode   | Implied

The `RTS` instruction shifts execution from a called subroutine to the previously executing code by reading the new Program Counter value from the stack.

## `JMP` - Unconditional Jump

`JMP` instructions perform an unconditional jump. They follow the specifications described in [Jump Operations](#jump-operations).

## `JO` - Jump if Overflow

`JO` instructions perform a conditional jump. They follow the specifications described in [Jump Operations](#jump-operations).

Flag Condition: `V = 1`
Signedness: -

## `JNO` - Jump if not Overflow

`JNO` instructions perform a conditional jump. They follow the specifications described in [Jump Operations](#jump-operations).

Flag Condition: `V = 0`
Signedness: -

## `JS` - Jump if Sign

`JS` instructions perform a conditional jump. They follow the specifications described in [Jump Operations](#jump-operations).

Flag Condition: `N = 1`
Signedness: -

## `JNS` - Jump if not Sign

`JNS` instructions perform a conditional jump. They follow the specifications described in [Jump Operations](#jump-operations).

Flag Condition: `N = 0`
Signedness: -

## `JE` - Jump if Equal

`JE` instructions perform a conditional jump. They follow the specifications described in [Jump Operations](#jump-operations).

Flag Condition: `Z = 1`
Signedness: -

## `JNE` - Jump if not Equal

`JNE` instructions perform a conditional jump. They follow the specifications described in [Jump Operations](#jump-operations).

Flag Condition: `Z = 0`
Signedness: -

## `JC` - Jump if Carry

`JC` instructions perform a conditional jump. They follow the specifications described in [Jump Operations](#jump-operations).

Flag Condition: `C = 1`
Signedness: unsigned

## `JNC` - Jump if not Carry

`JNC` instructions perform a conditional jump. They follow the specifications described in [Jump Operations](#jump-operations).

Flag Condition: `C = 0`
Signedness: unsigned

## `JBE` - Jump if Below or Equal

`JBE` instructions perform a conditional jump. They follow the specifications described in [Jump Operations](#jump-operations).

Flag Condition: `C = 1` or `Z = 1`
Signedness: unsigned

## `JA` - Jump if Above

`JA` instructions perform a conditional jump. They follow the specifications described in [Jump Operations](#jump-operations).

Flag Condition: `C = 0` and `Z = 0`
Signedness: unsigned

## `JL` - Jump if Less

`JL` instructions perform a conditional jump. They follow the specifications described in [Jump Operations](#jump-operations).

Flag Condition: `N != V`
Signedness: signed

## `JGE` - Jump if Greater or Equal

`JGE` instructions perform a conditional jump. They follow the specifications described in [Jump Operations](#jump-operations).

Flag Condition: `N = V`
Signedness: signed

## `JLE` - Jump if Less or Equal

`JLE` instructions perform a conditional jump. They follow the specifications described in [Jump Operations](#jump-operations).

Flag Condition: `Z = 1` or `N != V`
Signedness: signed

## `JG` - Jump if Greater

`JG` instructions perform a conditional jump. They follow the specifications described in [Jump Operations](#jump-operations).

Flag Condition: `Z = 0` and `N = V`
Signedness: signed

# Binary Math Operations

Binary Math Instructions are Arithmetic or Logical instructions which have two operands. In the BW8 ISA, these include the following:

1. `ADC`
2. `SBB`
3. `AND`
4. `OR`
5. `XOR`

These instructions have left and right hand side operands. The left hand operand also serves as the destination of the result. The left hand side operand is referred to as the destination, and the right hand side operand is referred to as the source: `bin_op dst src`.

Destinations: GPRs or Direct Page location
Sources: GPRs, Direct Page location, or immediate value

- When `dst` and `src` are both GPRs, they are allowed to be identical. Left shifts are supported via this mechanism.
- Both the `dst` and `src` may not be Direct Page locations.

Binary Math Instructions which are 3 bytes in size - this occurs when `dst` is a Direct Page location and `src` is an immediate value - are of the `NRM` type. Otherwise, they are of the `EXT` type.

# Unary Math Operations

Unary Math Operations are Arithmetic and Logical instructions which have one operand. In the BW8 ISA, these include the following:

1. `NOT`
2. `NEG`
3. `LSR`
4. `LRC`
5. `ASR`

These instructions have a single operand, which is used as both the source and the destination: `uny_op src`. The source is either a GPR, or a Direct Page location.

Addressing Modes:

**Implied**

Size: 2
Cycles: TBD

**Direct Page**

Size: 3
Cycles: TBD

All Unary Math Operations are of the `EXT` type.

# Jump Operations

Field | Value
--- | ---
Type | varies
Size | varies
Cycles | varies
Mode | varies

Jump instructions shift the execution path by moving the source into the Program Counter. This jump may be performed conditionally, based on the value of specific flags in the Status Register, or unconditionally. The source of the new execution point comes from the Addressing Mode. All jumps in the BW8 ISA support the same Addressing Modes. The mode also informs the type and size of the instruction.

Addressing Modes:

**Absolute**

Type: `NRM`
Size: 3
Cycles: TBD

**Relative**

Type: `NRM`
Size: 2
Cycles: TBD

**Indirect**

Indirection Sources: GPPs
Type: `EXT`
Size: 2
Cycles: TBD

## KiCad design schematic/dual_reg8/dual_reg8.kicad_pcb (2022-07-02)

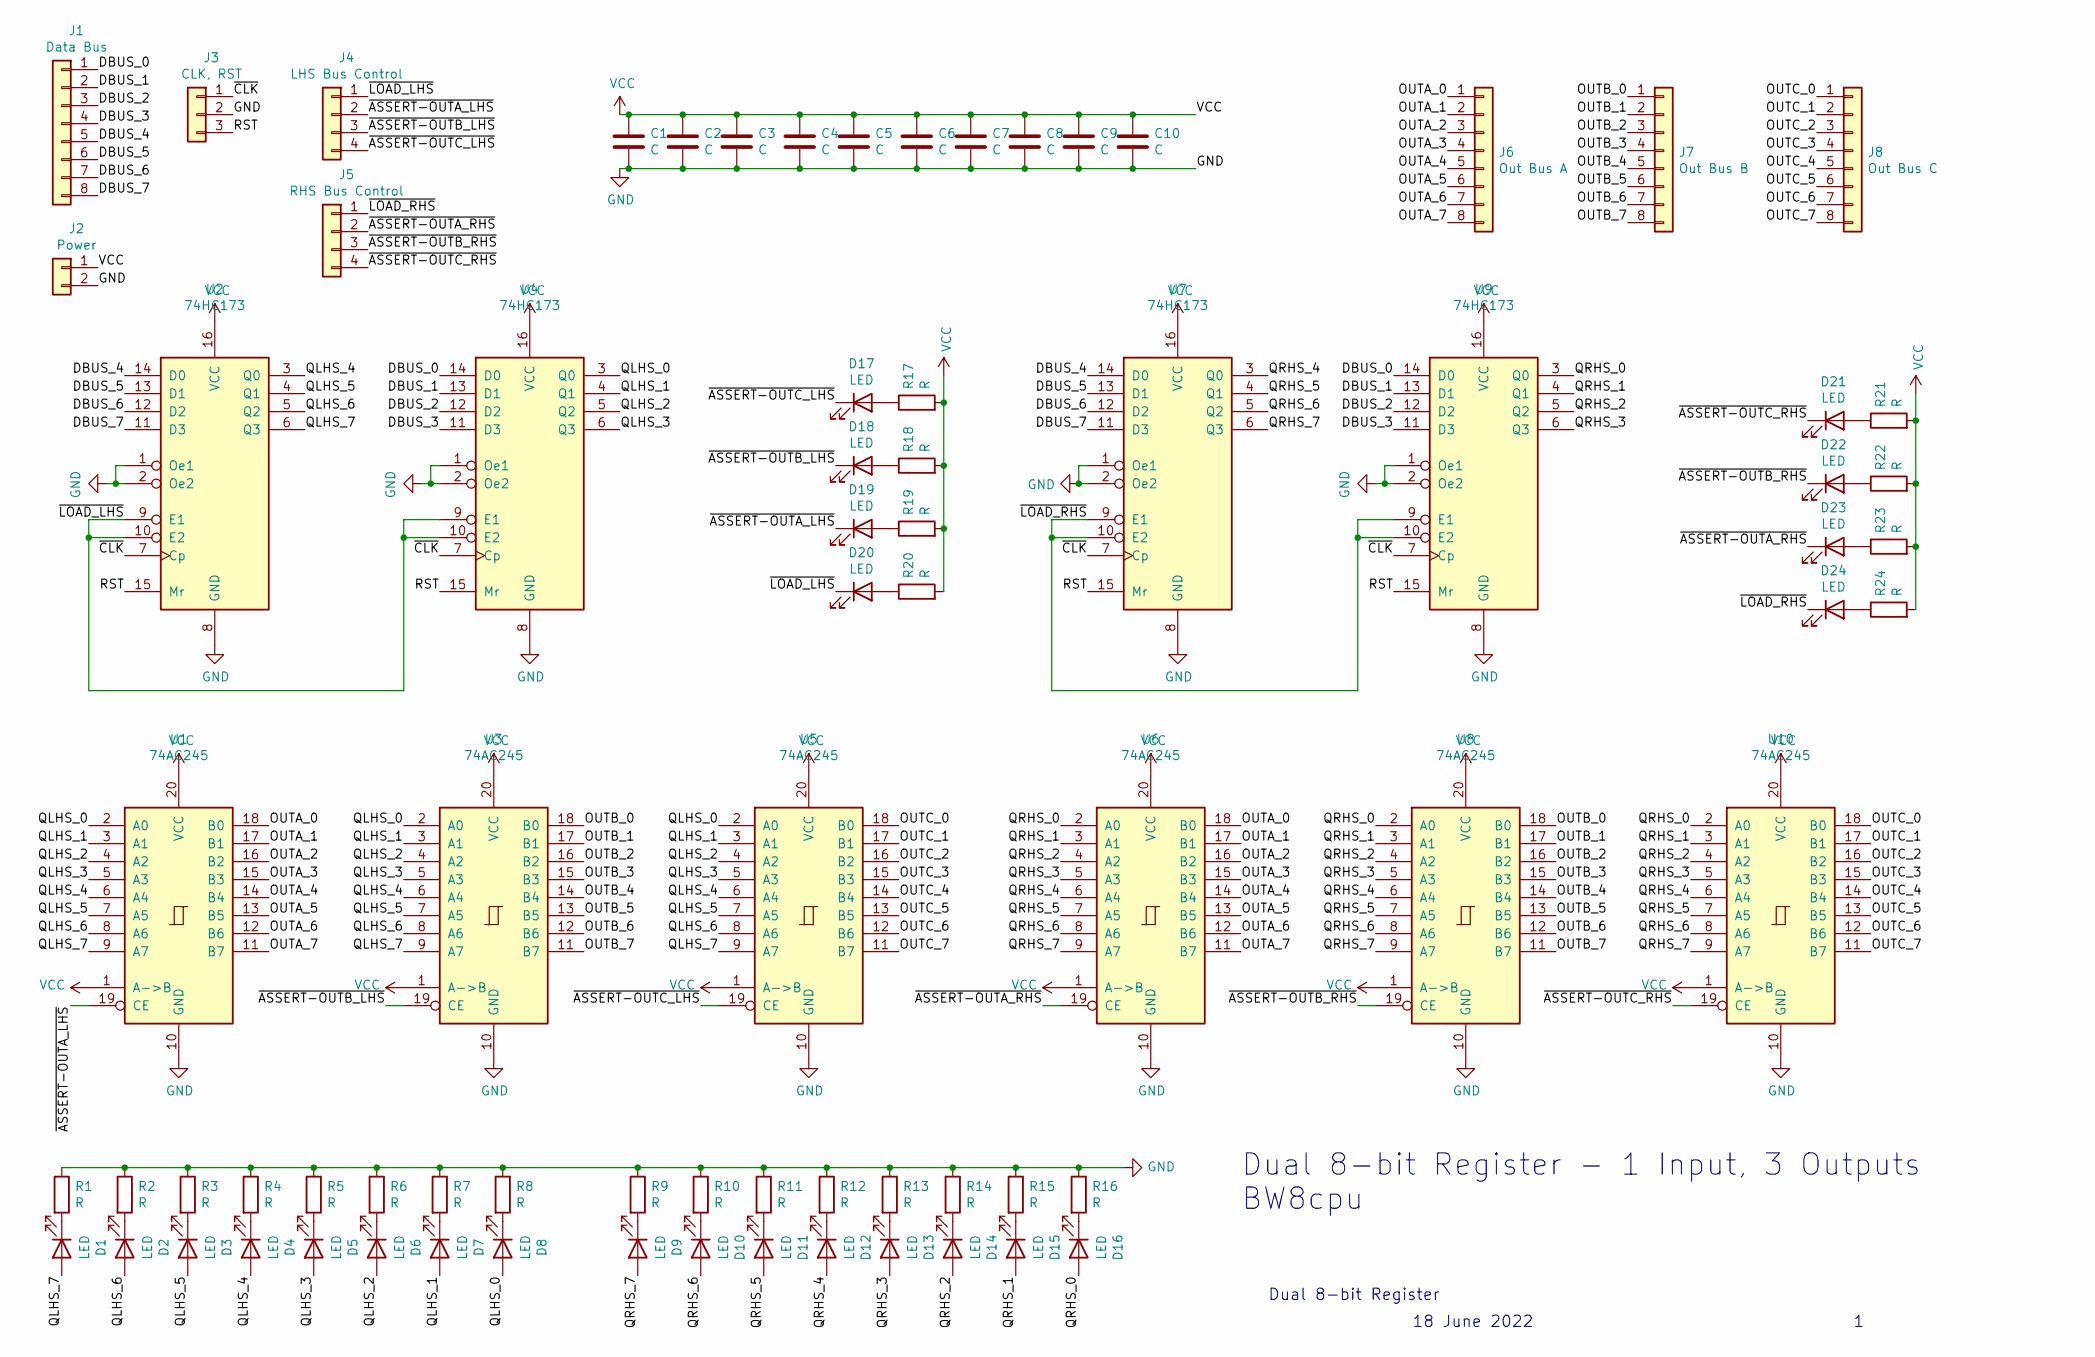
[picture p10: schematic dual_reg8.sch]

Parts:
C1, C2, C3, C4, C5, C6, C7, C8, C9, C10: C; C_Disc_D3.0mm_W1.6mm_P2.50mm
D1, D2, D3, D4, D5, D6, D7, D8, D9, D10, D11, D12, D13, D14, D15, D16, D17, D18, D19, D20, D21, D22, D23, D24: LED; LED_D2.0mm_W4.8mm_H2.5mm_FlatTop
J1: Data Bus; PinSocket_1x08_P2.54mm_Vertical
J2: Power; PinSocket_1x02_P2.54mm_Vertical
J3: CLK, RST; PinSocket_1x03_P2.54mm_Vertical
J4: LHS Bus Control; PinSocket_1x04_P2.54mm_Vertical
J5: RHS Bus Control; PinSocket_1x04_P2.54mm_Vertical
J6: Out Bus A; PinSocket_1x08_P2.54mm_Vertical
J7: Out Bus B; PinSocket_1x08_P2.54mm_Vertical
J8: Out Bus C; PinSocket_1x08_P2.54mm_Vertical
R1, R2, R3, R4, R5, R6, R7, R8, R9, R10, R11, R12, R13, R14, R15, R16, R17, R18, R19, R20, R21, R22, R23, R24: R; R_Axial_DIN0204_L3.6mm_D1.6mm_P5.08mm_Horizontal
U1, U3, U5, U6, U8, U10: 74AC245; DIP-20_W7.62mm
U2, U4, U7, U9: 74HC173; DIP-16_W7.62mm

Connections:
/DBUS_0: J1.1, U4.14 (D0), U9.14 (D0)
/DBUS_1: J1.2, U4.13 (D1), U9.13 (D1)
/DBUS_2: J1.3, U4.12 (D2), U9.12 (D2)
/DBUS_3: J1.4, U4.11 (D3), U9.11 (D3)
/DBUS_4: J1.5, U2.14 (D0), U7.14 (D0)
/DBUS_5: J1.6, U2.13 (D1), U7.13 (D1)
/DBUS_6: J1.7, U2.12 (D2), U7.12 (D2)
/DBUS_7: J1.8, U2.11 (D3), U7.11 (D3)
/OUTA_0: J6.1, U1.18 (B0), U6.18 (B0)
/OUTA_1: J6.2, U1.17 (B1), U6.17 (B1)
/OUTA_2: J6.3, U1.16 (B2), U6.16 (B2)
/OUTA_3: J6.4, U1.15 (B3), U6.15 (B3)
/OUTA_4: J6.5, U1.14 (B4), U6.14 (B4)
/OUTA_5: J6.6, U1.13 (B5), U6.13 (B5)
/OUTA_6: J6.7, U1.12 (B6), U6.12 (B6)
/OUTA_7: J6.8, U1.11 (B7), U6.11 (B7)
/OUTB_0: J7.1, U3.18 (B0), U8.18 (B0)
/OUTB_1: J7.2, U3.17 (B1), U8.17 (B1)
/OUTB_2: J7.3, U3.16 (B2), U8.16 (B2)
/OUTB_3: J7.4, U3.15 (B3), U8.15 (B3)
/OUTB_4: J7.5, U3.14 (B4), U8.14 (B4)
/OUTB_5: J7.6, U3.13 (B5), U8.13 (B5)
/OUTB_6: J7.7, U3.12 (B6), U8.12 (B6)
/OUTB_7: J7.8, U3.11 (B7), U8.11 (B7)
/OUTC_0: J8.1, U5.18 (B0), U10.18 (B0)
/OUTC_1: J8.2, U5.17 (B1), U10.17 (B1)
/OUTC_2: J8.3, U5.16 (B2), U10.16 (B2)
/OUTC_3: J8.4, U5.15 (B3), U10.15 (B3)
/OUTC_4: J8.5, U5.14 (B4), U10.14 (B4)
/OUTC_5: J8.6, U5.13 (B5), U10.13 (B5)
/OUTC_6: J8.7, U5.12 (B6), U10.12 (B6)
/OUTC_7: J8.8, U5.11 (B7), U10.11 (B7)
/QLHS_0: D8.2 (A), U1.2 (A0), U3.2 (A0), U4.3 (Q0), U5.2 (A0)
/QLHS_1: D7.2 (A), U1.3 (A1), U3.3 (A1), U4.4 (Q1), U5.3 (A1)
/QLHS_2: D6.2 (A), U1.4 (A2), U3.4 (A2), U4.5 (Q2), U5.4 (A2)
/QLHS_3: D5.2 (A), U1.5 (A3), U3.5 (A3), U4.6 (Q3), U5.5 (A3)
/QLHS_4: D4.2 (A), U1.6 (A4), U2.3 (Q0), U3.6 (A4), U5.6 (A4)
/QLHS_5: D3.2 (A), U1.7 (A5), U2.4 (Q1), U3.7 (A5), U5.7 (A5)
/QLHS_6: D2.2 (A), U1.8 (A6), U2.5 (Q2), U3.8 (A6), U5.8 (A6)
/QLHS_7: D1.2 (A), U1.9 (A7), U2.6 (Q3), U3.9 (A7), U5.9 (A7)
/QRHS_0: D16.2 (A), U6.2 (A0), U8.2 (A0), U9.3 (Q0), U10.2 (A0)
/QRHS_1: D15.2 (A), U6.3 (A1), U8.3 (A1), U9.4 (Q1), U10.3 (A1)
/QRHS_2: D14.2 (A), U6.4 (A2), U8.4 (A2), U9.5 (Q2), U10.4 (A2)
/QRHS_3: D13.2 (A), U6.5 (A3), U8.5 (A3), U9.6 (Q3), U10.5 (A3)
/QRHS_4: D12.2 (A), U6.6 (A4), U7.3 (Q0), U8.6 (A4), U10.6 (A4)
/QRHS_5: D11.2 (A), U6.7 (A5), U7.4 (Q1), U8.7 (A5), U10.7 (A5)
/QRHS_6: D10.2 (A), U6.8 (A6), U7.5 (Q2), U8.8 (A6), U10.8 (A6)
/QRHS_7: D9.2 (A), U6.9 (A7), U7.6 (Q3), U8.9 (A7), U10.9 (A7)
/RST: J3.3, U2.15 (Mr), U4.15 (Mr), U7.15 (Mr), U9.15 (Mr)
/~ASSERT-OUTA_LHS: D19.1 (K), J4.2, U1.19 (CE)
/~ASSERT-OUTA_RHS: D23.1 (K), J5.2, U6.19 (CE)
/~ASSERT-OUTB_LHS: D18.1 (K), J4.3, U3.19 (CE)
/~ASSERT-OUTB_RHS: D22.1 (K), J5.3, U8.19 (CE)
/~ASSERT-OUTC_LHS: D17.1 (K), J4.4, U5.19 (CE)
/~ASSERT-OUTC_RHS: D21.1 (K), J5.4, U10.19 (CE)
/~CLK: J3.1, U2.7 (Cp), U4.7 (Cp), U7.7 (Cp), U9.7 (Cp)
/~LOAD_LHS: D20.1 (K), J4.1, U2.9 (E1), U2.10 (E2), U4.9 (E1), U4.10 (E2)
/~LOAD_RHS: D24.1 (K), J5.1, U7.9 (E1), U7.10 (E2), U9.9 (E1), U9.10 (E2)
GND: C1.2, C2.2, C3.2, C4.2, C5.2, C6.2, C7.2, C8.2, C9.2, C10.2, J2.2, J3.2, R1.1, R2.1, R3.1, R4.1, R5.1, R6.1, R7.1, R8.1, R9.1, R10.1, R11.1, R12.1, R13.1, R14.1, R15.1, R16.1, U1.10 (GND), U2.1 (Oe1), U2.2 (Oe2), U2.8 (GND), U3.10 (GND), U4.1 (Oe1), U4.2 (Oe2), U4.8 (GND), U5.10 (GND), U6.10 (GND), U7.1 (Oe1), U7.2 (Oe2), U7.8 (GND), U8.10 (GND), U9.1 (Oe1), U9.2 (Oe2), U9.8 (GND), U10.10 (GND)
unnamed: D1.1 (K), R1.2
unnamed: D2.1 (K), R2.2
unnamed: D3.1 (K), R3.2
unnamed: D4.1 (K), R4.2
unnamed: D5.1 (K), R5.2
unnamed: D6.1 (K), R6.2
unnamed: D7.1 (K), R7.2
unnamed: D8.1 (K), R8.2
unnamed: D9.1 (K), R9.2
unnamed: D10.1 (K), R10.2
unnamed: D11.1 (K), R11.2
unnamed: D12.1 (K), R12.2
unnamed: D13.1 (K), R13.2
unnamed: D14.1 (K), R14.2
unnamed: D15.1 (K), R15.2
unnamed: D16.1 (K), R16.2
unnamed: D17.2 (A), R17.1
unnamed: D18.2 (A), R18.1
unnamed: D19.2 (A), R19.1
unnamed: D20.2 (A), R20.1
unnamed: D21.2 (A), R21.1
unnamed: D22.2 (A), R22.1
unnamed: D23.2 (A), R23.1
unnamed: D24.2 (A), R24.1
VCC: C1.1, C2.1, C3.1, C4.1, C5.1, C6.1, C7.1, C8.1, C9.1, C10.1, J2.1, R17.2, R18.2, R19.2, R20.2, R21.2, R22.2, R23.2, R24.2, U1.1 (A->B), U1.20 (VCC), U2.16 (VCC), U3.1 (A->B), U3.20 (VCC), U4.16 (VCC), U5.1 (A->B), U5.20 (VCC), U6.1 (A->B), U6.20 (VCC), U7.16 (VCC), U8.1 (A->B), U8.20 (VCC), U9.16 (VCC), U10.1 (A->B), U10.20 (VCC)

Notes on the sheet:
Dual 8-bit Register - 1 Input, 3 Outputs BW8cpu
18 June 2022
Dual 8-bit Register

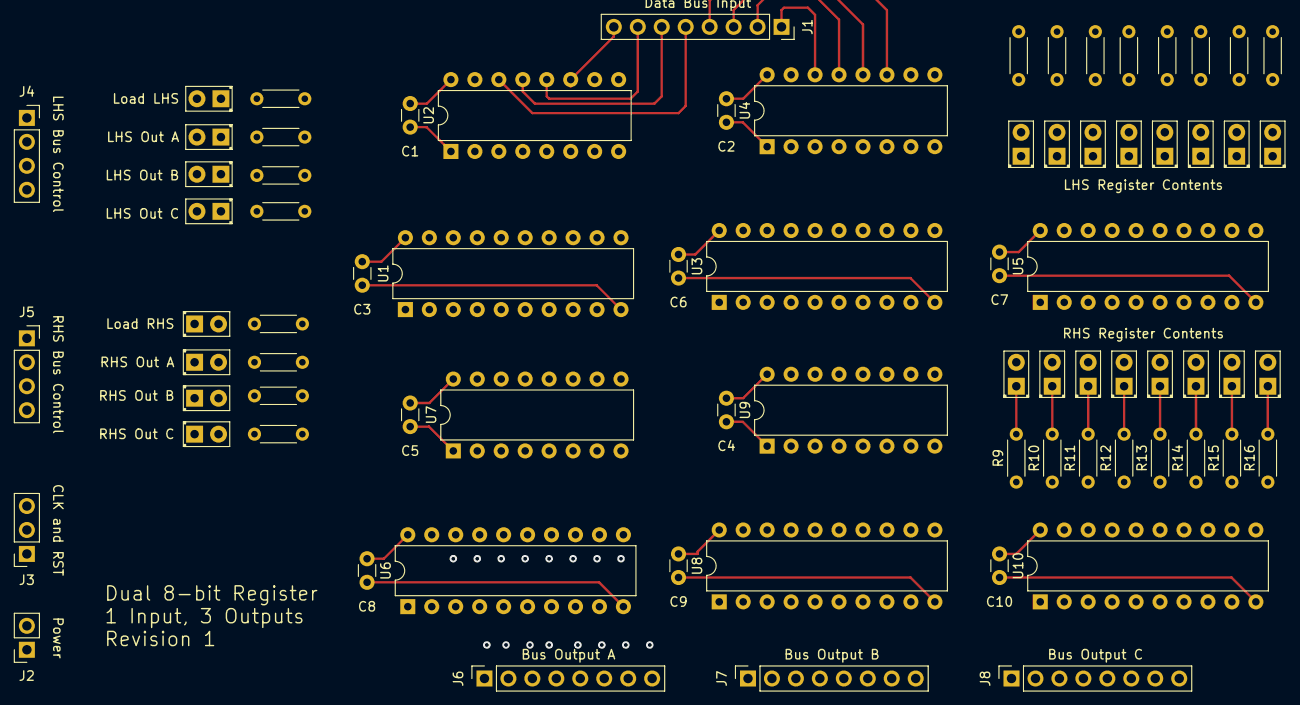
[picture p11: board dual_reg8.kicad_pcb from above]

Board: 2 copper layers, 76 parts (0 on the bottom side), 84 nets.

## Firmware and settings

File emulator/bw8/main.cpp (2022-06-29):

#define _CRT_SECURE_NO_WARNINGS

#include <stdlib.h>
#include <stdio.h>

#ifdef _WIN32
#include <Windows.h>
#else
#include <unistd.h>
#endif

#include "bw8cpu.h"
#include "bw8bus.h"


int main(int argc, char** argv) {
    bool dump = false;

    if (argc < 2) {
        fprintf(stderr, "usage: bw8.exe <rom_path>");
        exit(-1);
    }

    BW8::Bus bus = BW8::Bus(argv[1]);

    bus.rst(true);
    bus.rst(false);

    while (true) {
        bus.clock();
        bus.dump(stdout);
        if (bus.hlt()) {
            bus.coredump();
        }
    }
}

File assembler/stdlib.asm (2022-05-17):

#include "bw8cpu.asm"

; Calling Conventions:
; Caller Saved Registers: A, B, Y
; Callee Saved Registers: C, D, X

; X is used as Frame Pointer
; A, B, and Y are used for function arguments
; Excess arguments are on the stack, directly below
; the Return Address

; Return Values are in A or AB.


; Adds two unsigned 16-bit numbers
; Arguments:
;   AB: 16-bit unsigned number, operand1
;   Y:  16-bit unsigned number, operand2
; Returns:
;   AB: 16-bit unsigned number, operand1 + operand2
uadd16:
    ; Prolouge
    push c
    push d
    ; No need for FP or locals

    mov cd, y

    clc
    adc b, d
    adc a, c

    ; Epilouge
    pop d
    pop c
    rts

; Subtracts two unsigned 16-bit numbres
; Arguments:
;   AB: 16-bit unsigned number, operand1
;   Y:  16-bit unsigned number, operand2
; Returns:
;   AB: 16-bit unsigned number, operand1 - operand2
usub16:
    ; Prolouge
    push c
    push d

    mov cd, y

    sec
    sbc b, d
    sbc a, c

    ; Epilouge
    pop d
    pop c
    rts

; Convert an ASCII HEX character to its corresponding
; numerical value
; eg, "0" -> 0b00000000, "1" -> "0b00000001", "F" -> 0b00001111
; Arguments:
;   A: 8-bit ASCII code. Must be "0"-"9" or "A"-"F"
; Returns:
;   A: 8-bit numerical value, or -1 if ASCII value was not valid
atoi8:
    ; If value is less than "0", then can't be 0-9 or A-F, so arg is invalid
    load b, #"0"
    cmp a, b
    jl .invalid_arg

    ; If value is greater than "F", then can't be 0-9 or A-F, so arg is invalid
    load b, #"F"
    cmp a, b
    jg .invalid_arg

    ; offset the value by the position of "0" if the value was decimal, then this
    ; is the value otherwise, its either alphabetical or invalid.
    sec
    sbc a, #"0"
    cmp a, #("9" - "0")
    jg .is_alpha
    jmp .return

    .is_alpha:
        cmp a, #("A" - "0")
        jl .invalid_arg
        cmp a, #("F" - "0")
        jg .invalid_arg

        sec
        sbc a, #"A"

        ; Value is now 0-5, corresponding to "A" to "F"
        ; and needs to be mapped into 10-15
        ; so add the value to 10 and return it

        load b, #10
        clc
        adc a, b
        jmp .return

    .invalid_arg:
        load a, #-1

    .return:
        rts

; Convert two ASCII HEX characters to its corresponding
; numerical value
; Arguments:
;   A: 8-bit ASCII HEX character. The high byte.
;   B: 8-bit ASCII HEX character. The low byte.
; Returns:
;   A: 8-bit numerical value representative of the ASCII input.
;   B: denote error code. 0 denotes success.
atoi16:
    ; Prolouge
    push c

    ; Move lower byte into A and compute
    ; lower nibble, then check for success
    push a
    mov a, b
    jsr atoi8
    cmp a, #-1
    je .invalid_args

    ; Move low nibble to B, retrieve higher byte
    ; from stack, and backup B (caller-saved register)
    ; check for success
    mov b, a
    pop a
    push b
    jsr atoi8
    cmp a, #-1
    je .invalid_args

    ; Now, high nibble is in low 4 bits of A. So shift left 4 bits
    load b, #4
    jsr shl_n

    ; Retrieve low nibble from stack, combine
    ; the nibbles by ANDing, denote success
    ; then return
    pop b
    and a, b
    load b, #0
    jmp .return

    .invalid_args:
        ; atoi8 put -1 in A for us, so just move
        ; that to B
        mov b, a

    .return:
        ; Epilouge
        pop c
        rts

; Given a byte, returns 2 ASCII characters that represent it
; in hexadecimal notation.
; Arguments:
;   A: the byte to convert.
; Returns:
;   A: the ASCII char representing the high nibble.
;   B: the ASCII char representing the low nibble.
itoa8:
    ; Prolouge
    push c
    push x

    ; backup input argument in B
    mov b, a

    ; clear out high 4 bits from the arg
    and a, #0b0000_1111

    ; Read the Ath element from the array into C. This is the high byte.
    load x, #.hex_array
    load c, [x, a]

    ; Restore argument from b, logically shift it right 4 bits
    mov a, b
    load b, #4
    jsr shr_n

    ; Read Ath element from array in B. This is the low byte.
    ; Also return high byte from C to A.
    load b, [x, a]
    mov a, c

    ; Epilouge
    pop x
    pop c
    rts

    .hex_array:
        #d "0123456789ABCDEF"


; Perform a left shift of the specified number of bits.
; Arguments:
;   A: the value to shift.
;   B: the number of bits to shift.
; Returns:
;   A: the shifted value.
shl_n:
    .loop_control:
        cmp b, #-1
        jg .loop_body
        jmp .loop_exit

    .loop_body:
        clc
        adc a, a

        dec b
        jmp .loop_control

    .loop_exit:
        rts

; Perform a logical right shift without carry of the specified number of bits.
; Arguments:
;   A: the value to shift.
;   B: the number of bits to shift.
; Returns:
;   A: the shifted value.
shr_n:
    .loop_control:
        cmp b, #-1
        jg .loop_body
        jmp .loop_exit

    .loop_body:
        clc
        src a

        dec b
        jmp .loop_control

    .loop_exit:
        rts

; Perform a logical shift right without carry of the specified number of bits.
; Arguments:
;   A: the value to shift.
;   B: the number of bits to shift
; Returns:
;   A: the shifted value.
shr_n_optimized:
    ; Mask the top 5 bits so that B between 0 and 7
    and b, #0b0000_0111

    ; Offset into the table should be 2 x B since the label table has 16 bit words
    ; (I think.. should that table label be aligned?)
    clc
    adc b, b

    ; Load the base pointer, add the computed offset, then jump on it.
    load y, #.shift_table
    lea y, b
    jmp y

    .b7:
        src a
    .b6:
        src a
    .b5:
        src a
    .b4:
        src a
    .b3:
        src a
    .b2:
        src a
    .b1:
        src a

        ; mask away the carried-in bits
        load y, #.mask_table
        clc
        src b
        load b, [y, b]
        and a, b

    .b0:
        rts

    .mask_table:    ; TODO: get the correct masks here
        #d8 0x7F, 0x3F, 0x1F, 0xF0, 0x70, 0x30, 0x10, 0x00
    .shift_table:
        #d16 .b0, .b1, .b2, .b3, .b4, .b5, .b6, .b7

; Perform an arithmetic right shift of the specified number of bits.
; Arguments:
;   A: the value to shift.
;   B: the number of bits to shift.
; Returns:
;   A: the shifted value.
asr_n:
    .loop_control:
        cmp b, #-1
        jg .loop_body
        jmp .loop_exit

    .loop_body:
        asr a

        dec b
        jmp .loop_control

    .loop_exit:
        rts
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

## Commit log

2021-03-30 moved existing logisim circuit to sap1.circ, began custom design in existing file
2021-07-13 gitignore update, dont track pdf or txt
2021-11-18 checkin kicad schematics
    [adr.kicad_pcb, adr.sch, alu.kicad_pcb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]
2021-11-18 removed some schematic and all logisim files
2021-11-18 renamed asm folder to assembler
2021-11-23 repo cleanup
    [adr.kicad_pcb, adr.sch, alu.kicad_pcb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]
2021-11-27 new ctrl encodings for DPI and SPI constants
2022-01-01 slight cleanup. divided opcodes into instruction pages.
    [opcode_matrix.xlsx]
2022-01-14 assembler definition beginnings!
2022-01-14 more assembly definitions
2022-01-20 new bitfield patterns for subruledef in microcode assembly file
2022-01-23 updated opcode assigner to include secondary byte to denote which instruction page each instruction belongs to
    [opcode_matrix.xlsx]
2022-02-07 updated assembly definition
2022-03-12 updated memory map description to current plans
2022-03-28 updated assembler to match new instruction set
2022-04-21 start of an assembly standard library
2022-04-21 fixed spacing in assembler definition file
2022-06-20 mega simulator progress
    [adr.sch, alu.kicad_pcb, alu.sch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]
2022-06-24 emulator work, UART partially working
2022-06-29 working UART!
2022-06-29 SR fixed for interrupts
2022-07-02 switching branches, cleaning tree
    [dual_reg8.kicad_pcb, dual_reg8.sch]
2022-08-27 cleaning source tree to switch branches
